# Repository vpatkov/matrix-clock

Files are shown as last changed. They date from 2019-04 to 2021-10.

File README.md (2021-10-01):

# Matrix Clock with Weather Station

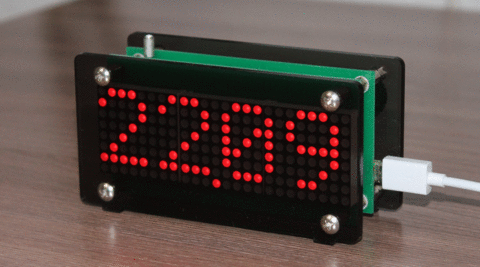
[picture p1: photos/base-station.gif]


Not too small, not too big, auto-syncing clock with wide viewing angle,
pretty bright at sunny day and not too bright at night, having a
simple weather station, without any wires except a Micro-USB power.

- Show clock, outdoor and indoor temperatures, indoor relative humidity, and
  atmospheric pressure
- Show the peak values and the change of any weather parameter for 24 hours
- Clock is wirelessly synced with a PC and maintained when the PC is offline
- Automatic brightness control
- Intuitively controlled with a single clickable rotary encoder on the back side

The project includes a base station with a LED matrix display, and two
wireless modules: one is for measuring outdoor temperature, and one is for
communication with a PC (syncing time).

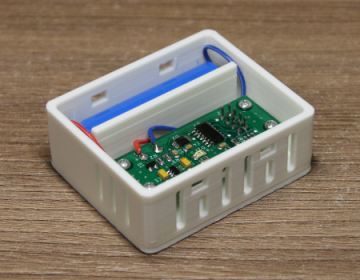
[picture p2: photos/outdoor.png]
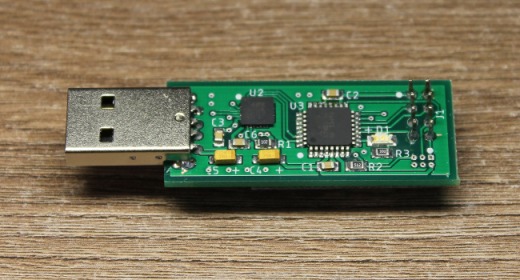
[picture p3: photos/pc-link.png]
 

If, for some reason, the base station conclude that some data is unreliable, it
show the latest reliable data with a warning mark as a point in the bottom
right corner. Clock is unreliable if not synced with a PC for a week. Outdoor
temperature is unreliable if no data was received from the outdoor sensor for
10 minutes. Data from indoor sensors is unreliable in case of any error.

If the battery in the outdoor module is low, a warning mark as a point in
the top right corner appears on the outdoor temperature screen.

It's a project I made for personal use in 2014 with some updates then.
It's based on my own preferences and ad hoc decisions. Also, it's my first
real-world electronic project after "LED blinking", and so have many design
lacks.

## Technical details

The base station is a sandwich of two boards called in sources as `base` and
`matrix`. The `base` board contains an MCU, indoor sensors, RF module, and other
peripherals. The `matrix` board is just a SPI controlled 24×8 LED matrix.

The wireless modules are called in sources as `outdoor` (outdoor temperature
measurement) and `pc-link` (communication with a PC). The `pc-link` module
is connected to a PC by USB, and appears as a virtual serial port (CP2102N chip
is used for that). CP2102N also feeds 1 MHz clock to the MCU, the chip
must be configured for that with Silabs' [configuration tool](https://www.silabs.com/products/development-tools/software/simplicity-studio).
The `pc-link` module is controlled by a host program `matrix-clock` (in the
`software` directory). Currently, the program is used just for sending
current time to the base station (add it to cron).

The wireless network is build on Nordic NRF24L01+ chips.

The front and rear glasses for the base station are made in
[Ponoko](https://www.ponoko.com/) by laser cutting from "acrylic gray tint"
material using the `case/base-station.svg` file.

The case for the outdoor module is 3D printed from the `case/outdoor-case.stl`
and `case/outdoor-cover.stl` files.

## License

Creative Commons Zero 1.0



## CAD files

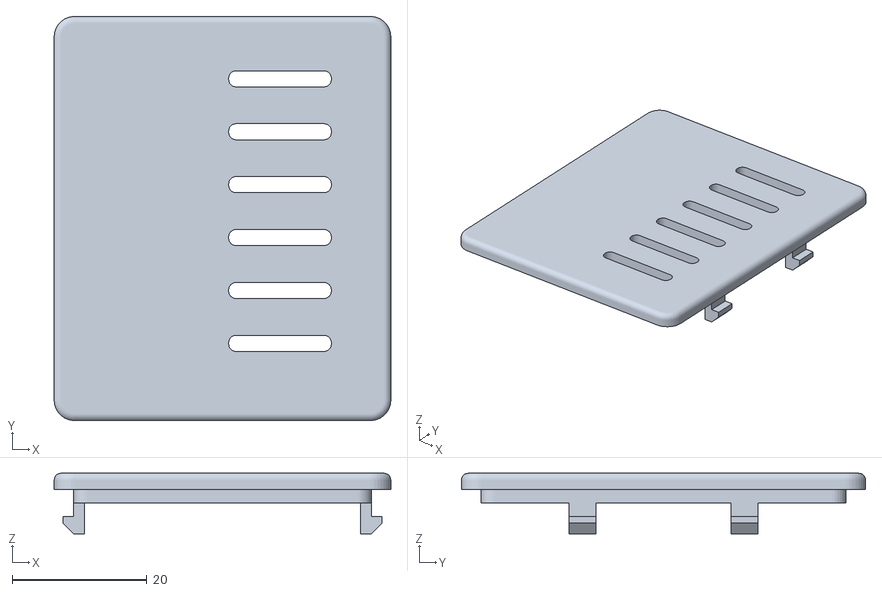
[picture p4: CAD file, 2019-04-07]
case/outdoor-cover.stl
50.0 x 60.0 x 9.00

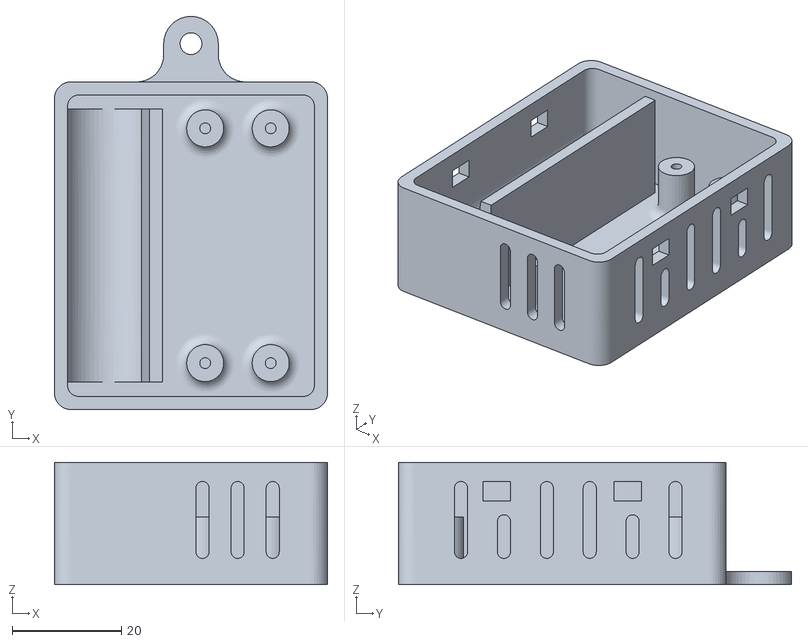
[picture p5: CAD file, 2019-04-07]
case/outdoor-case.stl
50.0 x 72.0 x 22.4

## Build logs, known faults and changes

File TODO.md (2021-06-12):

Remake from scratch:

- Don't remake wireless modules (`pc-link` and `outdoor`), they are ok.
  Some cosmetic fixes maybe.
- Single board, use small SMD components. For ISP programming use pogo pads
  (like in the wireless modules).
- Try to put all the sensors on a single bus (I2C or SPI).
- Don't use breakout boards. Maybe except NRF24L01+, but solder it directly
  (like in the wireless modules).
- Don't use 32k crystal, use a single 8M XO oscillator.
- Maybe serial interface (CP2102N) for changing settings, debugging, etc.
- Maybe emergency battery to keep the RTC. Maybe an RTC chip.
- Log weather and send it to the PC.
- CO2 sensor?
- Buzzer
- Fully enclose in a 3D printed case.

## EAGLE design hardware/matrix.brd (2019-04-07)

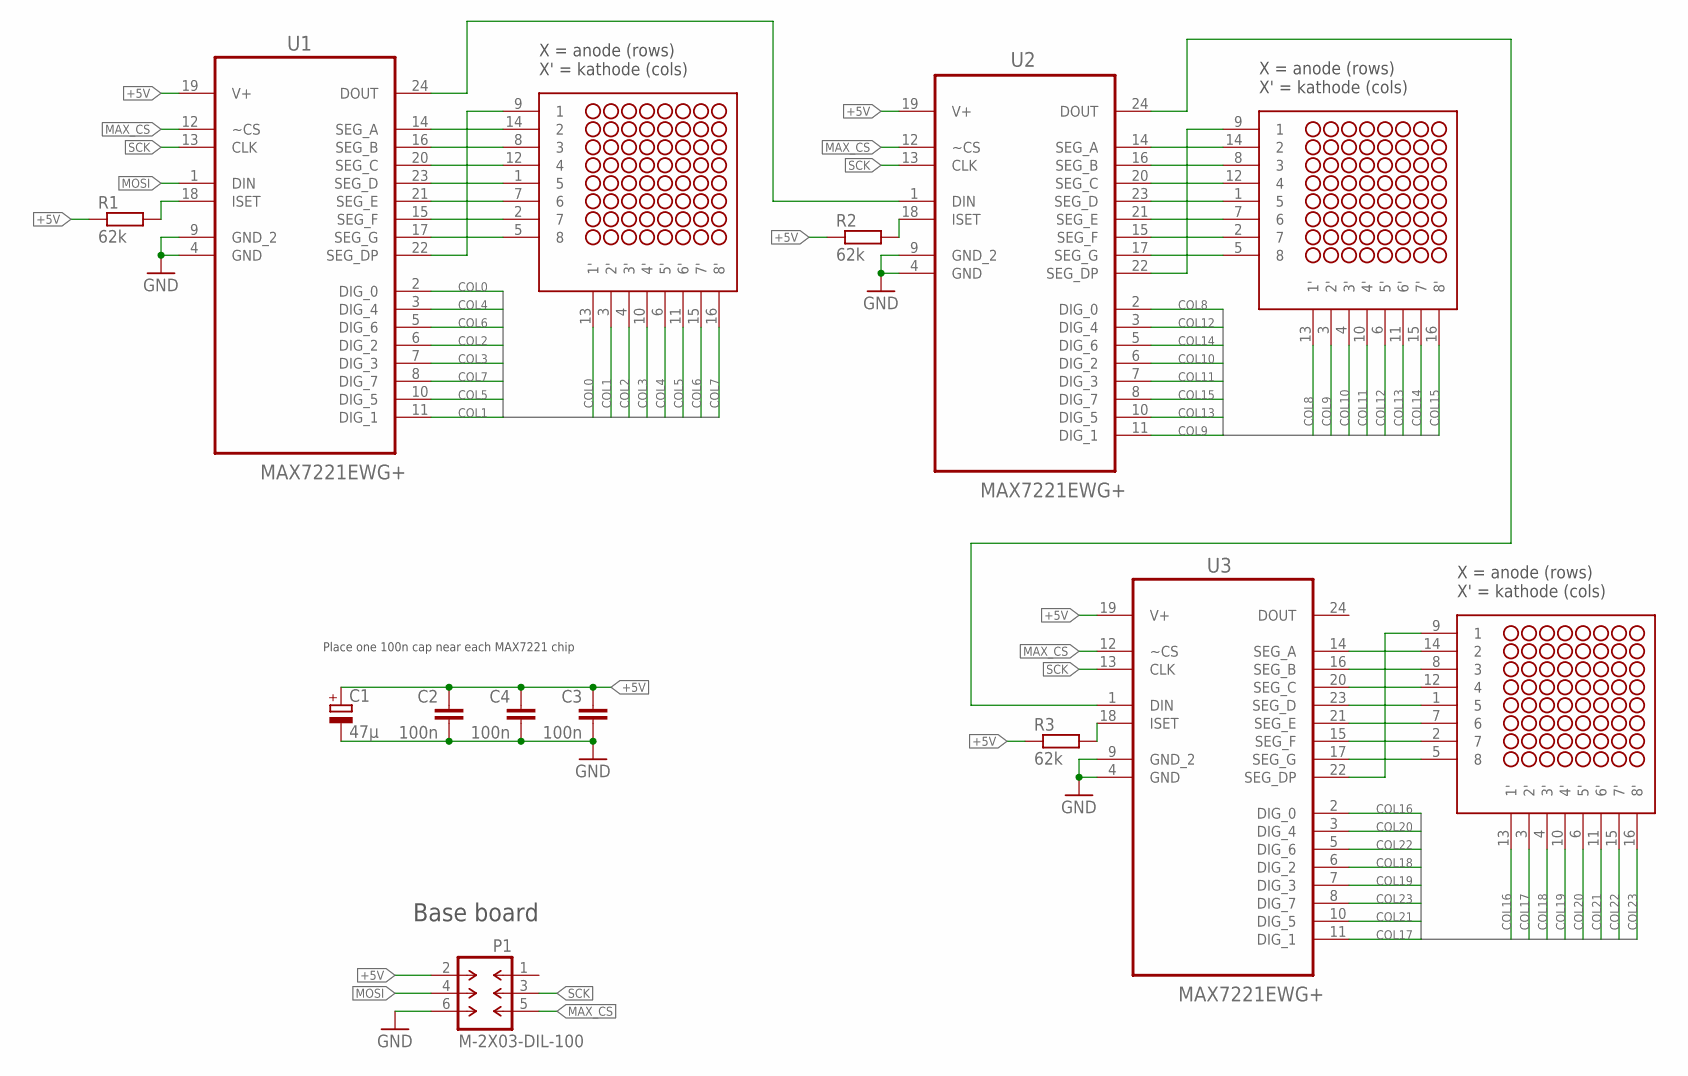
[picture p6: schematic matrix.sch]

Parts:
C1: 47μ; D/7343-31W
C2, C3, C4: 100n; C1206
M1, M2, M3: 1088BS; NFM-12881BG-11
P1: M-2X03-DIL-100; DIL-100-2X03
R1, R2, R3: 62k; R1206
U1, U2, U3: MAX7221EWG+; SOIC127P1032X265-24N

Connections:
+5V: C1.+, C2.1, C3.1, C4.1, P1.2, R1.1, R2.1, R3.1, U1.19 (V+), U2.19 (V+), U3.19 (V+)
COL0: M1.13 (1'), U1.2 (DIG_0)
COL1: M1.3 (2'), U1.11 (DIG_1)
COL2: M1.4 (3'), U1.6 (DIG_2)
COL3: M1.10 (4'), U1.7 (DIG_3)
COL4: M1.6 (5'), U1.3 (DIG_4)
COL5: M1.11 (6'), U1.10 (DIG_5)
COL6: M1.15 (7'), U1.5 (DIG_6)
COL7: M1.16 (8'), U1.8 (DIG_7)
COL8: M2.13 (1'), U2.2 (DIG_0)
COL9: M2.3 (2'), U2.11 (DIG_1)
COL10: M2.4 (3'), U2.6 (DIG_2)
COL11: M2.10 (4'), U2.7 (DIG_3)
COL12: M2.6 (5'), U2.3 (DIG_4)
COL13: M2.11 (6'), U2.10 (DIG_5)
COL14: M2.15 (7'), U2.5 (DIG_6)
COL15: M2.16 (8'), U2.8 (DIG_7)
COL16: M3.13 (1'), U3.2 (DIG_0)
COL17: M3.3 (2'), U3.11 (DIG_1)
COL18: M3.4 (3'), U3.6 (DIG_2)
COL19: M3.10 (4'), U3.7 (DIG_3)
COL20: M3.6 (5'), U3.3 (DIG_4)
COL21: M3.11 (6'), U3.10 (DIG_5)
COL22: M3.15 (7'), U3.5 (DIG_6)
COL23: M3.16 (8'), U3.8 (DIG_7)
GND: C1.-, C2.2, C3.2, C4.2, P1.6, U1.4 (GND), U1.9 (GND_2), U2.4 (GND), U2.9 (GND_2), U3.4 (GND), U3.9 (GND_2)
MAX_CS: P1.5, U1.12 (~CS), U2.12 (~CS), U3.12 (~CS)
MOSI: P1.4, U1.1 (DIN)
unnamed: M1.9 (1), U1.22 (SEG_DP)
unnamed: M1.5 (8), U1.17 (SEG_G)
unnamed: M1.2 (7), U1.15 (SEG_F)
unnamed: M1.7 (6), U1.21 (SEG_E)
unnamed: M1.1 (5), U1.23 (SEG_D)
unnamed: M1.12 (4), U1.20 (SEG_C)
unnamed: M1.8 (3), U1.16 (SEG_B)
unnamed: M1.14 (2), U1.14 (SEG_A)
unnamed: M2.9 (1), U2.22 (SEG_DP)
unnamed: M2.14 (2), U2.14 (SEG_A)
unnamed: M2.8 (3), U2.16 (SEG_B)
unnamed: M2.12 (4), U2.20 (SEG_C)
unnamed: M2.1 (5), U2.23 (SEG_D)
unnamed: M2.7 (6), U2.21 (SEG_E)
unnamed: M2.2 (7), U2.15 (SEG_F)
unnamed: M2.5 (8), U2.17 (SEG_G)
unnamed: M3.9 (1), U3.22 (SEG_DP)
unnamed: M3.5 (8), U3.17 (SEG_G)
unnamed: M3.2 (7), U3.15 (SEG_F)
unnamed: M3.7 (6), U3.21 (SEG_E)
unnamed: M3.1 (5), U3.23 (SEG_D)
unnamed: M3.12 (4), U3.20 (SEG_C)
unnamed: M3.8 (3), U3.16 (SEG_B)
unnamed: M3.14 (2), U3.14 (SEG_A)
unnamed: U1.24 (DOUT), U2.1 (DIN)
unnamed: U2.24 (DOUT), U3.1 (DIN)
unnamed: R1.2, U1.18 (ISET)
unnamed: R2.2, U2.18 (ISET)
unnamed: R3.2, U3.18 (ISET)
SCK: P1.3, U1.13 (CLK), U2.13 (CLK), U3.13 (CLK)

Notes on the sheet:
X = anode (rows) X' = kathode (cols)
Base board
Place one 100n cap near each MAX7221 chip

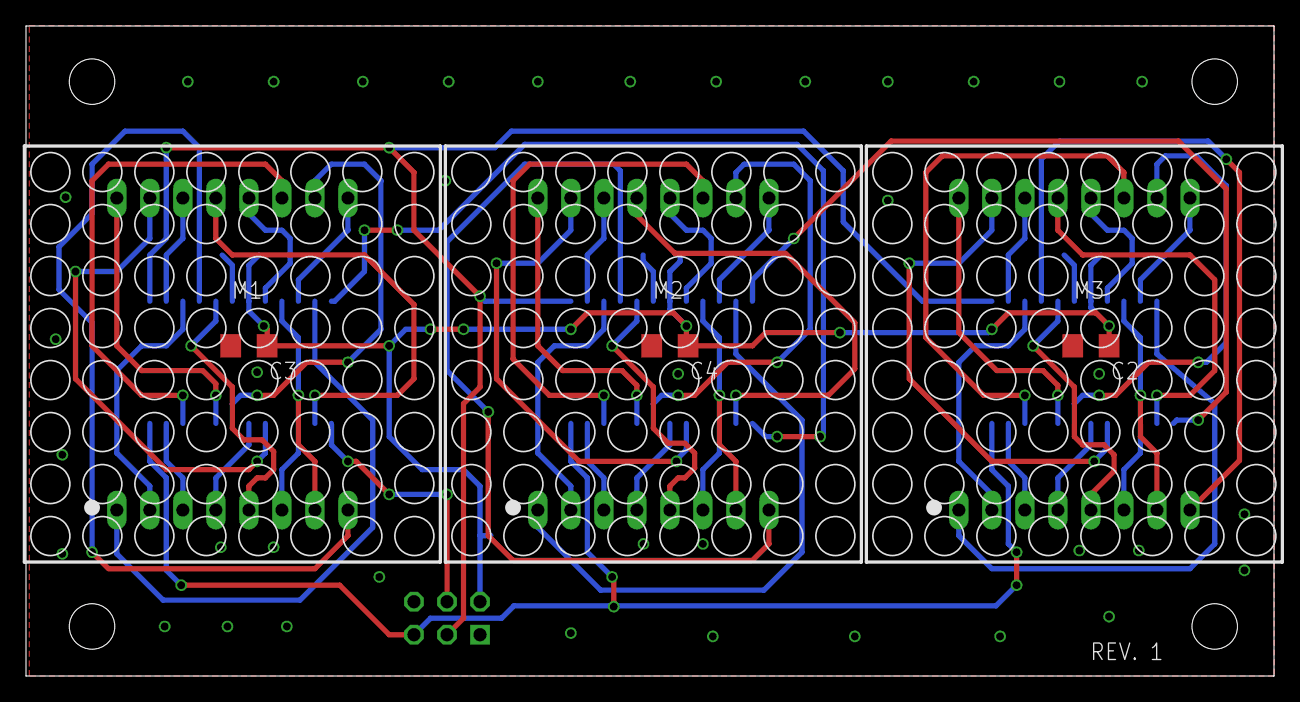
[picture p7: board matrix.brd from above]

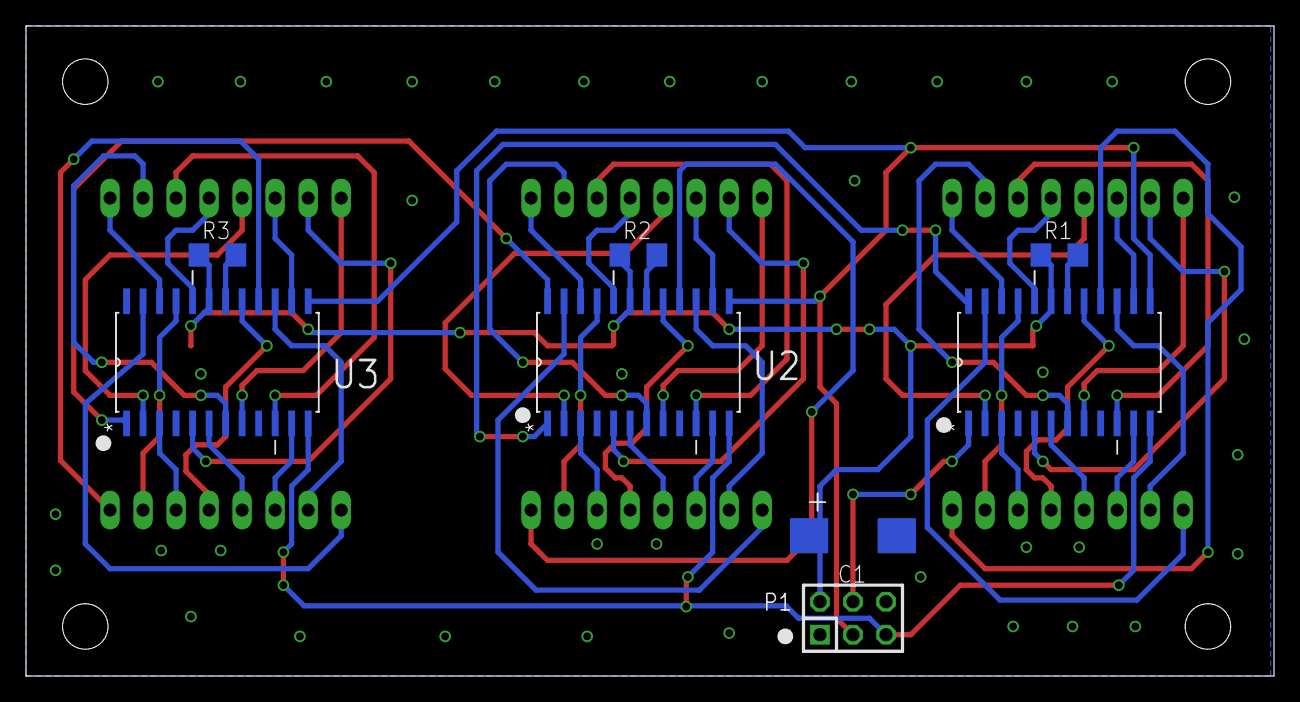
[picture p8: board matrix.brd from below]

Board: 2 copper layers, 96.0 x 50.0 mm, 14 parts (8 on the bottom side), 58 nets.

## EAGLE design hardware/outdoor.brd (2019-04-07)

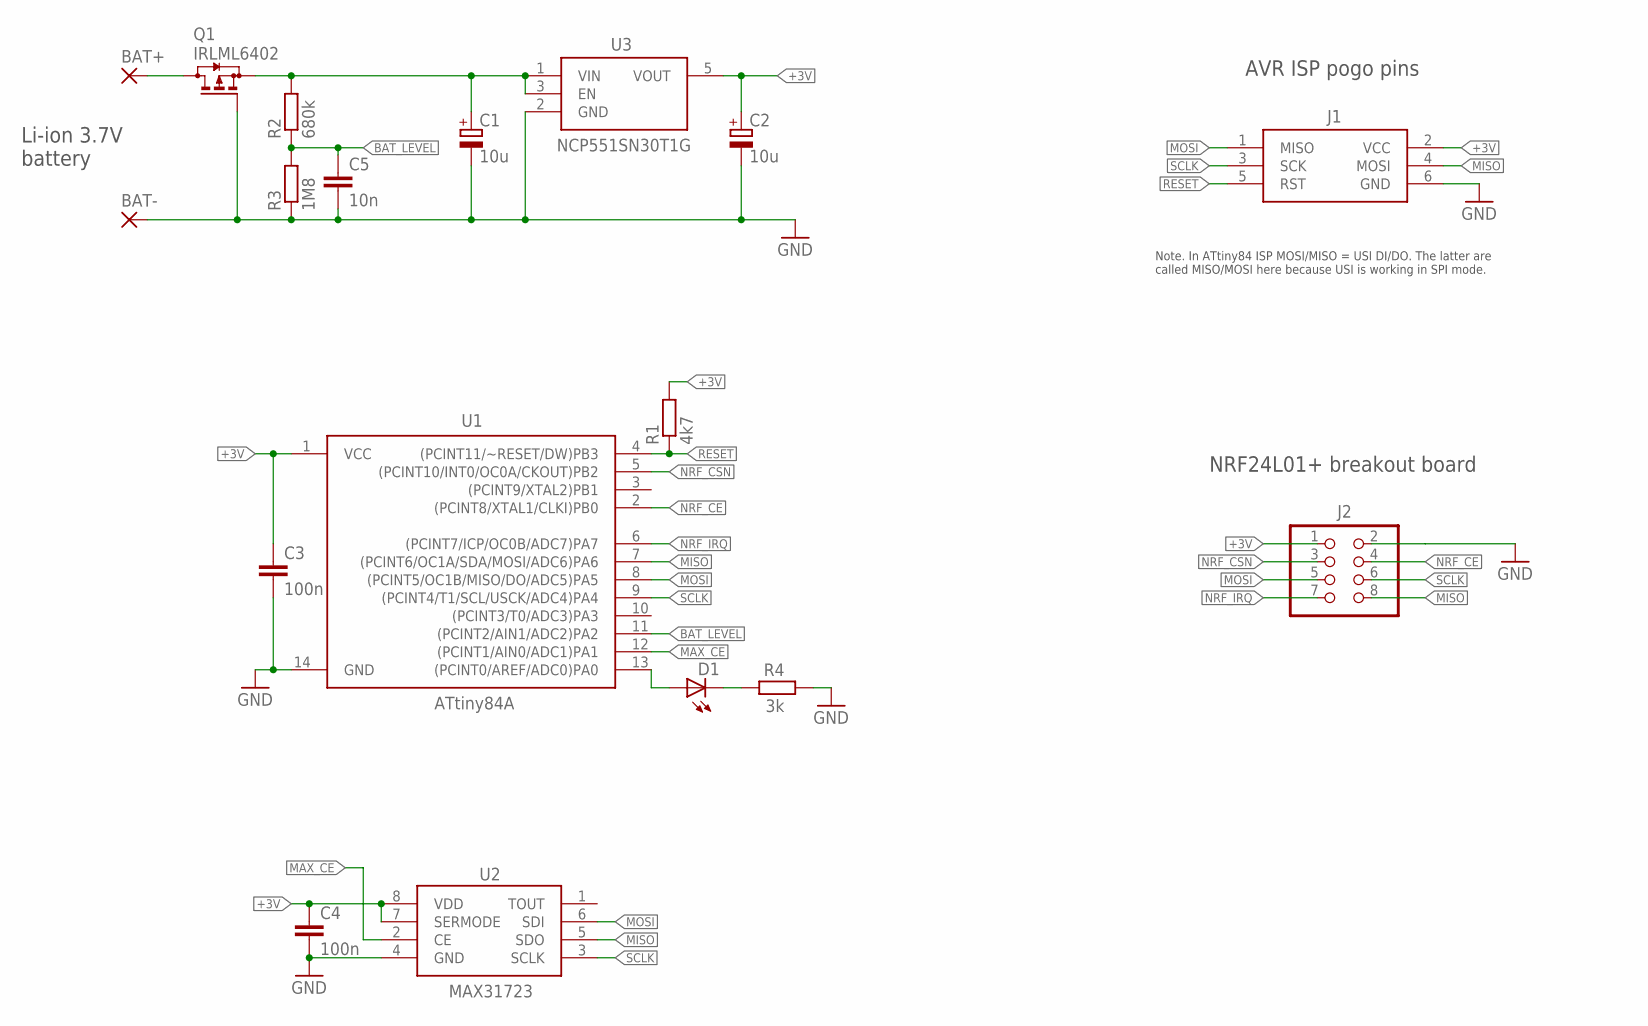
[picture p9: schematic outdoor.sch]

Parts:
BAT+: 2,54/1,0
BAT-: 2,54/1,0
C1, C2: 10u; CT3216
C3, C4: 100n; C0805
C5: 10n; C0805
D1: LEDSMT1206; 1206
J1: POGO_AVR_ISP6
J2: PINHD-2X4; 2X04
Q1: IRLML6402; SOT23
R1: 4k7; R0805
R2: 680k; R0805
R3: 1M8; R0805
R4: 3k; R0805
U1: ATtiny84A; SO14
U2: MAX31723; UMAX8
U3: NCP551SN30T1G; SOT23-5

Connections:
+3V: C2.+, C3.1, C4.1, J1.2 (VCC), J2.1, R1.2, U1.1 (VCC), U2.7 (SERMODE), U2.8 (VDD), U3.5 (VOUT)
BAT_LEVEL: C5.1, R2.1, R3.2, U1.11 ((PCINT2/AIN1/ADC2)PA2)
GND: BAT-.1, C1.-, C2.-, C3.2, C4.2, C5.2, J1.6 (GND), J2.2, Q1.1 (G), R3.1, R4.1, U1.14 (GND), U2.4 (GND), U3.2 (GND)
MAX_CE: U1.12 ((PCINT1/AIN0/ADC1)PA1), U2.2 (CE)
MISO: J1.4 (MOSI), J2.8, U1.7 ((PCINT6/OC1A/SDA/MOSI/ADC6)PA6), U2.5 (SDO)
MOSI: J1.1 (MISO), J2.5, U1.8 ((PCINT5/OC1B/MISO/DO/ADC5)PA5), U2.6 (SDI)
unnamed: BAT+.1, Q1.3 (D)
unnamed: C1.+, Q1.2 (S), R2.2, U3.1 (VIN), U3.3 (EN)
unnamed: D1.A, U1.13 ((PCINT0/AREF/ADC0)PA0)
unnamed: D1.C, R4.2
NRF_CE: J2.4, U1.2 ((PCINT8/XTAL1/CLKI)PB0)
NRF_CSN: J2.3, U1.5 ((PCINT10/INT0/OC0A/CKOUT)PB2)
NRF_IRQ: J2.7, U1.6 ((PCINT7/ICP/OC0B/ADC7)PA7)
RESET: J1.5 (RST), R1.1, U1.4 ((PCINT11/~RESET/DW)PB3)
SCLK: J1.3 (SCK), J2.6, U1.9 ((PCINT4/T1/SCL/USCK/ADC4)PA4), U2.3 (SCLK)

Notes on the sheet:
Li-ion 3.7V battery
Note. In ATtiny84 ISP MOSI/MISO = USI DI/DO. The latter are called MISO/MOSI here because USI is working in SPI mode.
AVR ISP pogo pins
NRF24L01+ breakout board

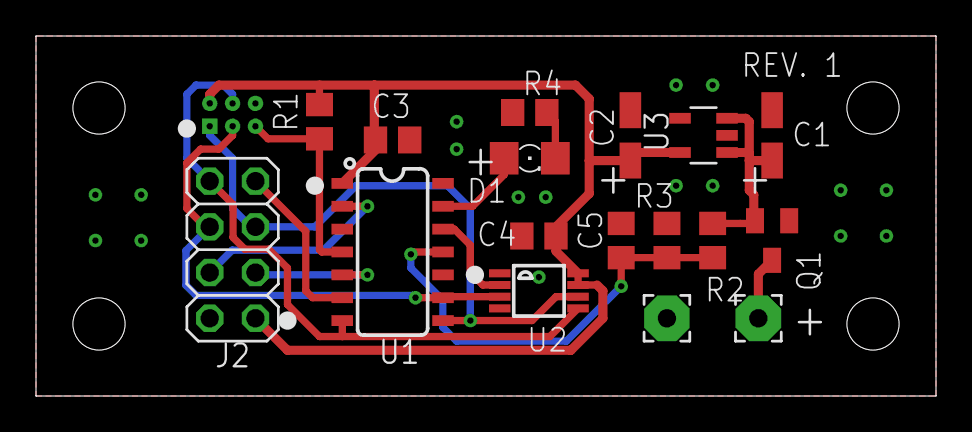
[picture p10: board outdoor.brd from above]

Board: 2 copper layers, 50.0 x 20.0 mm, 18 parts (0 on the bottom side), 15 nets.

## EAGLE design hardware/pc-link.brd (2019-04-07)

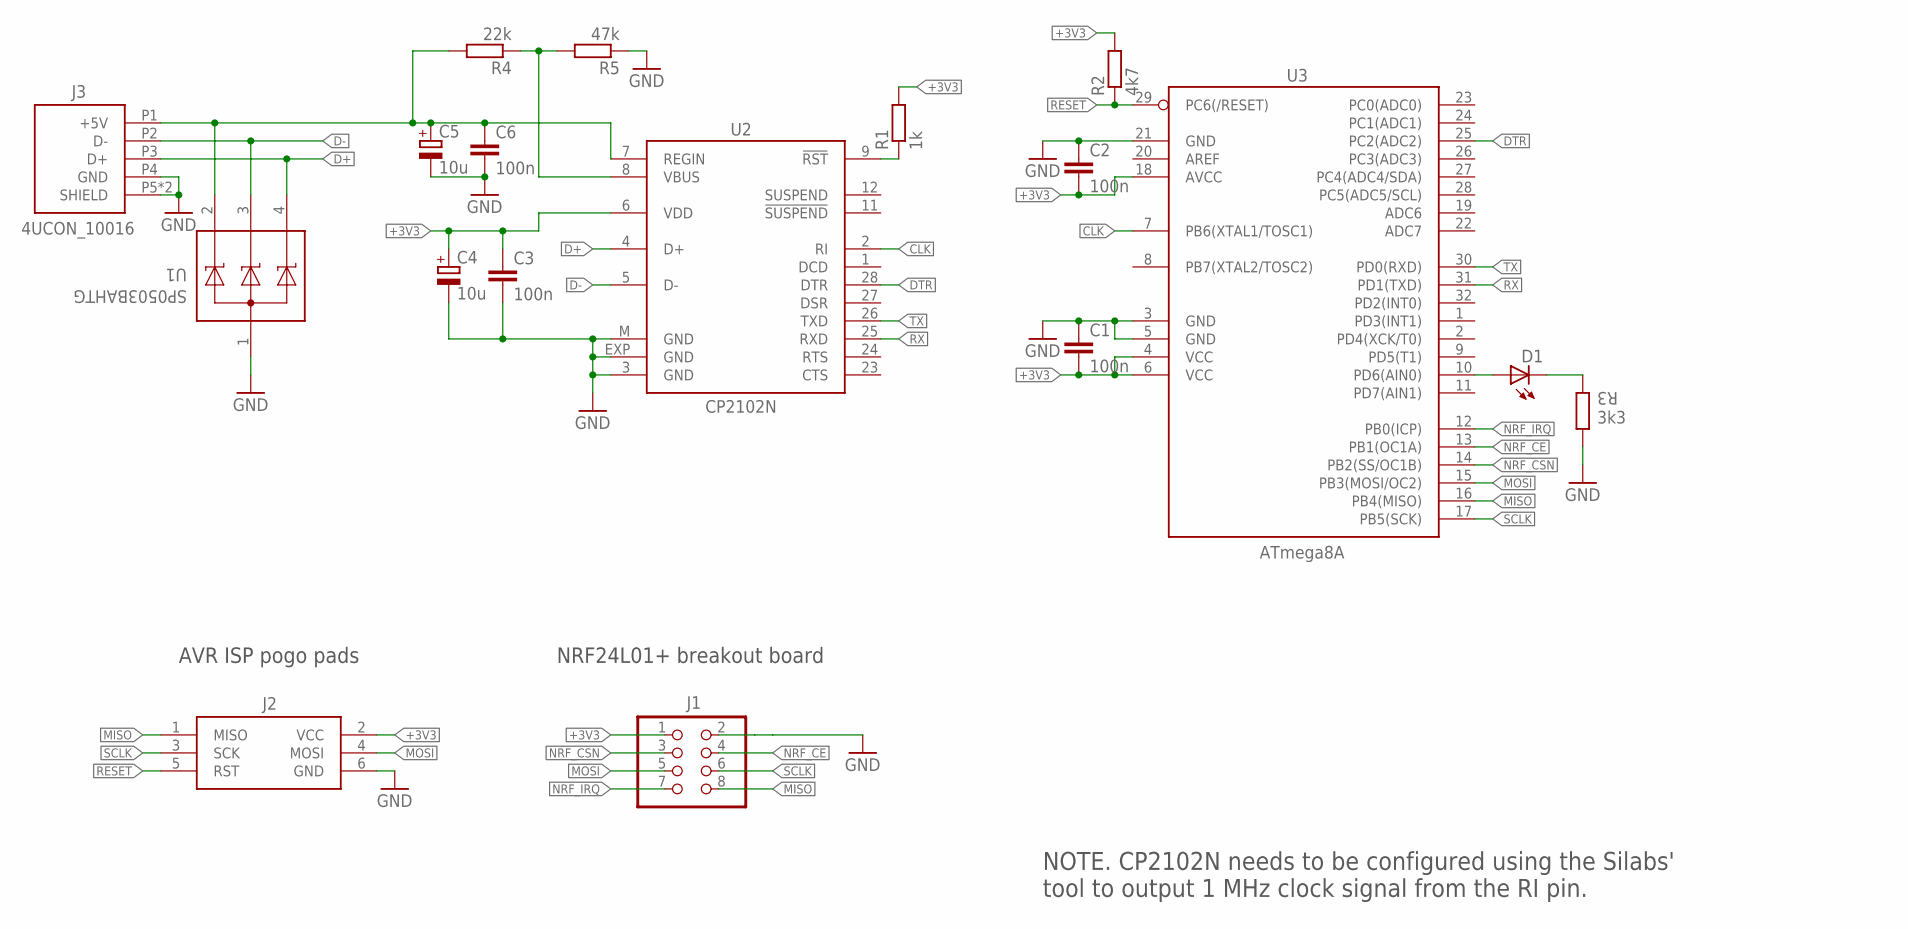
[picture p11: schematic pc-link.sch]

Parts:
C1, C2, C3, C6: 100n; C0805
C4, C5: 10u; CT3216
D1: LEDSMT1206; 1206
J1: PINHD-2X4; 2X04
J2: POGO_AVR_ISP6
J3: 4UCON_10016; USB_A_4UCON_10016
R1: 1k; R0805
R2: 4k7; R0805
R3: 3k3; R0805
R4: 22k; R0805
R5: 47k; R0805
U1: SP0503BAHTG; SOT143
U2: CP2102N; MLP28
U3: ATmega8A; TQFP32-08

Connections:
+3V3: C1.2, C2.2, C3.1, C4.+, J1.1, J2.2 (VCC), R1.2, R2.2, U2.6 (VDD), U3.4 (VCC), U3.6 (VCC), U3.18 (AVCC)
+5V: C5.+, C6.1, J3.P1 (+5V), R4.2, U1.2, U2.7 (REGIN)
CLK: U2.2 (RI), U3.7 (PB6(XTAL1/TOSC1))
D+: J3.P3 (D+), U1.4, U2.4 (D+)
D-: J3.P2 (D-), U1.3, U2.5 (D-)
DTR: U2.28 (DTR), U3.25 (PC2(ADC2))
GND: C1.1, C2.1, C3.2, C4.-, C5.-, C6.2, J1.2, J2.6 (GND), J3.P4 (GND), J3.P5 (SHIELD), J3.P6 (SHIELD), R3.1, R5.1, U1.1, U2.3 (GND), U2.EXP (GND), U2.M (GND), U3.3 (GND), U3.5 (GND), U3.21 (GND)
MISO: J1.8, J2.1 (MISO), U3.16 (PB4(MISO))
MOSI: J1.5, J2.4 (MOSI), U3.15 (PB3(MOSI/OC2))
unnamed: R1.1, U2.9 (!RST)
unnamed: D1.C, R3.2
unnamed: D1.A, U3.10 (PD6(AIN0))
unnamed: R4.1, R5.2, U2.8 (VBUS)
NRF_CE: J1.4, U3.13 (PB1(OC1A))
NRF_CSN: J1.3, U3.14 (PB2(SS/OC1B))
NRF_IRQ: J1.7, U3.12 (PB0(ICP))
RESET: J2.5 (RST), R2.1, U3.29 (PC6(/RESET))
RX: U2.25 (RXD), U3.31 (PD1(TXD))
SCLK: J1.6, J2.3 (SCK), U3.17 (PB5(SCK))
TX: U2.26 (TXD), U3.30 (PD0(RXD))

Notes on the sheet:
NOTE. CP2102N needs to be configured using the Silabs' tool to output 1 MHz clock signal from the RI pin.
NRF24L01+ breakout board
AVR ISP pogo pads

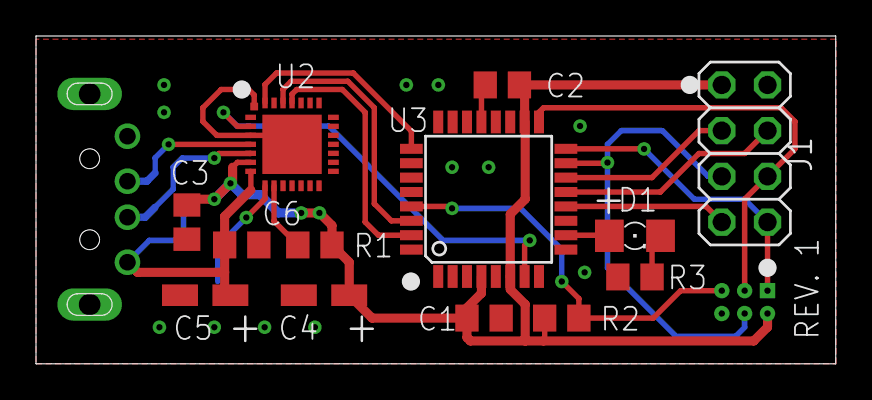
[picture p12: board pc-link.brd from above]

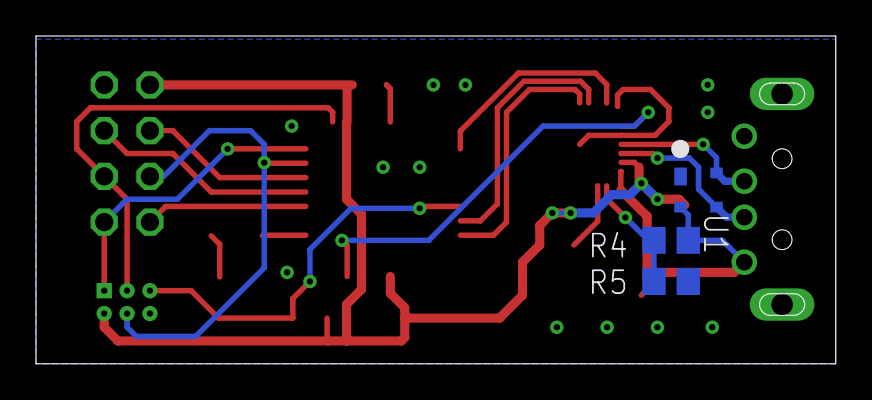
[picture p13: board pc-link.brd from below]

Board: 2 copper layers, 44.4 x 18.2 mm, 18 parts (3 on the bottom side), 20 nets.

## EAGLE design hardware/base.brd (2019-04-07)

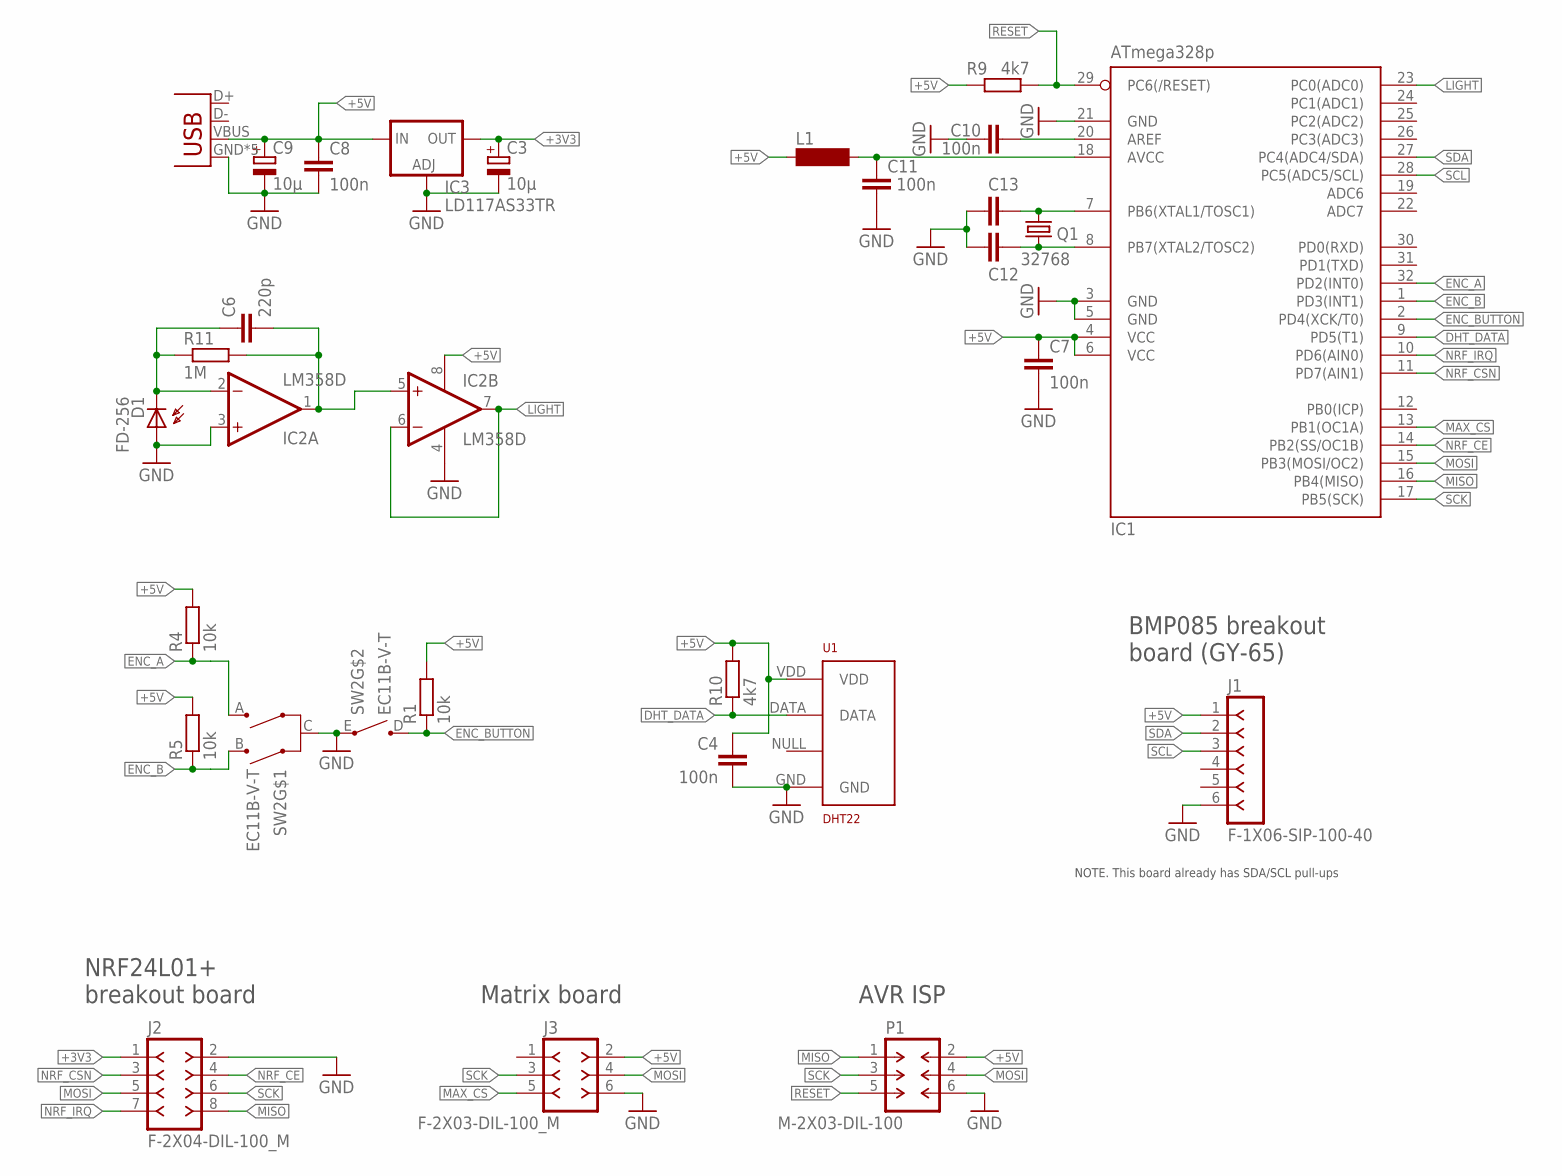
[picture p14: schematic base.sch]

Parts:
C3, C9: 10μ; D/7343-31R
C4, C8: 100n; C1206
C6: 220p; C1206
C7, C10, C11: 100n; C0805
C12, C13: C-EUC0805; C0805
D1: FD-256; BPX65
IC1: ATmega328p; TQFP32-08
IC2: LM358D; SO08
IC3: LD117AS33TR; SOT223
J1: F-1X06-SIP-100-40; SIP-100-06-40
J2: F-2X04-DIL-100_M; DIL-100-2X04_M
J3: F-2X03-DIL-100_M; DIL-100-2X03_M
JP5: USB-MICROB
L1: SM-1206
P1: M-2X03-DIL-100; DIL-100-2X03
Q1: 32768; TC26H
R1, R4, R5: 10k; R1206
R9, R10: 4k7; R1206
R11: 1M; R1206
SW2: EC11B-V-T; EC11B-V
U1: DHT22; RHT03_DHT-22/RA

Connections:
+3V3: C3.+, IC3.4 (OUT), J2.1
+5V: C4.1, C7.1, C8.1, C9.+, IC1.4 (VCC), IC1.6 (VCC), IC2.8 (V+), IC3.3 (IN), J1.1, J3.2, JP5.VBUS, L1.1, P1.2, R1.2, R4.2, R5.2, R9.2, R10.2, U1.VDD
DHT_DATA: IC1.9 (PD5(T1)), R10.1, U1.DATA
ENC_A: IC1.32 (PD2(INT0)), R4.1, SW2.A
ENC_B: IC1.1 (PD3(INT1)), R5.1, SW2.B
ENC_BUTTON: IC1.2 (PD4(XCK/T0)), R1.1, SW2.D
GND: C3.-, C4.2, C7.2, C8.2, C9.-, C10.2, C11.2, C12.2, C13.2, D1.A, IC1.3 (GND), IC1.5 (GND), IC1.21 (GND), IC2.3 (+IN), IC2.4 (V-), IC3.1 (ADJ), J1.6, J2.2, J3.6, JP5.GND, JP5.MT1 (GND), JP5.MT2 (GND), JP5.P$1 (GND), JP5.P$2 (GND), P1.6, SW2.C, SW2.E, U1.GND
LIGHT: C6.2, IC1.23 (PC0(ADC0)), IC2.1 (OUT), IC2.5 (+IN), IC2.6 (-IN), IC2.7 (OUT), R11.2
MAX_CS: IC1.13 (PB1(OC1A)), J3.5
MISO: IC1.16 (PB4(MISO)), J2.8, P1.1
MOSI: IC1.15 (PB3(MOSI/OC2)), J2.5, J3.4, P1.4
unnamed: C10.1, IC1.20 (AREF)
unnamed: C6.1, D1.K (C), IC2.2 (-IN), R11.1
unnamed: C11.1, IC1.18 (AVCC), L1.2
unnamed: C12.1, IC1.8 (PB7(XTAL2/TOSC2)), Q1.1
unnamed: C13.1, IC1.7 (PB6(XTAL1/TOSC1)), Q1.2
NRF_CE: IC1.14 (PB2(SS/OC1B)), J2.4
NRF_CSN: IC1.11 (PD7(AIN1)), J2.3
NRF_IRQ: IC1.10 (PD6(AIN0)), J2.7
RESET: IC1.29 (PC6(/RESET)), P1.5, R9.1
SCK: IC1.17 (PB5(SCK)), J2.6, J3.3, P1.3
SCL: IC1.28 (PC5(ADC5/SCL)), J1.3
SDA: IC1.27 (PC4(ADC4/SDA)), J1.2

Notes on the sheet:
BMP085 breakout board (GY-65)
NRF24L01+ breakout board
AVR ISP
Matrix board
NOTE. This board already has SDA/SCL pull-ups

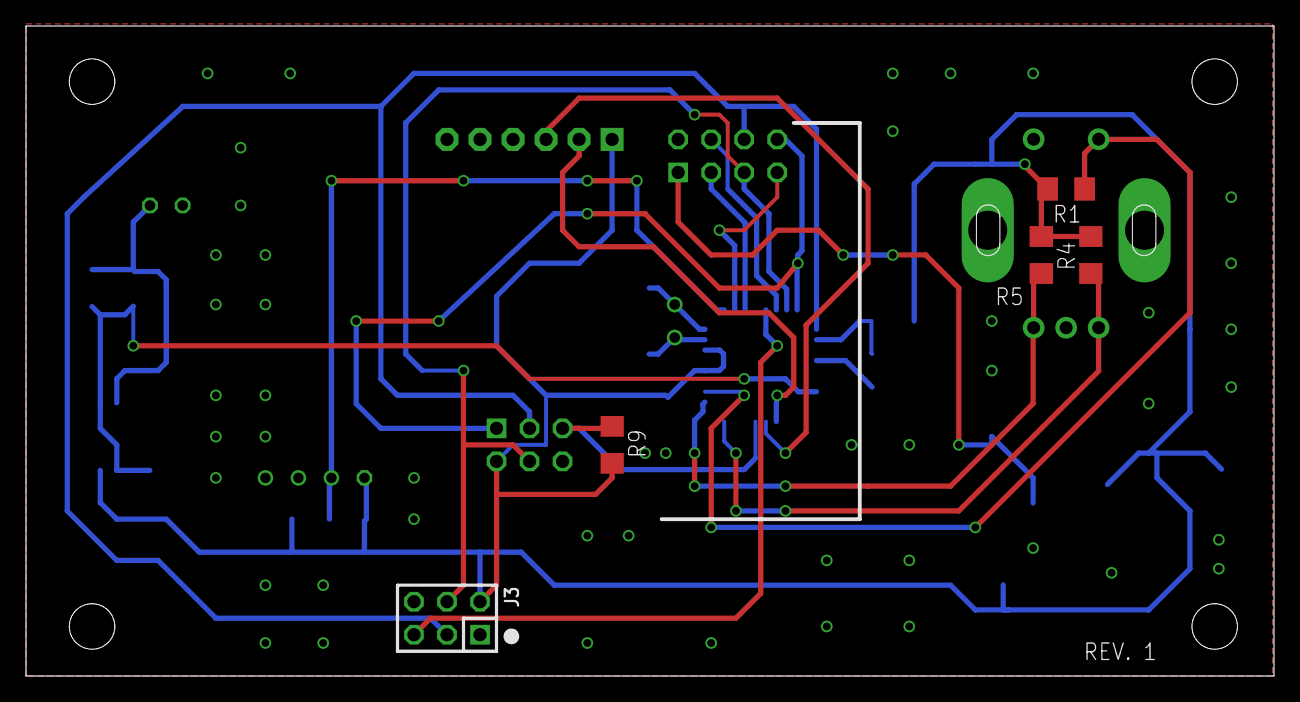
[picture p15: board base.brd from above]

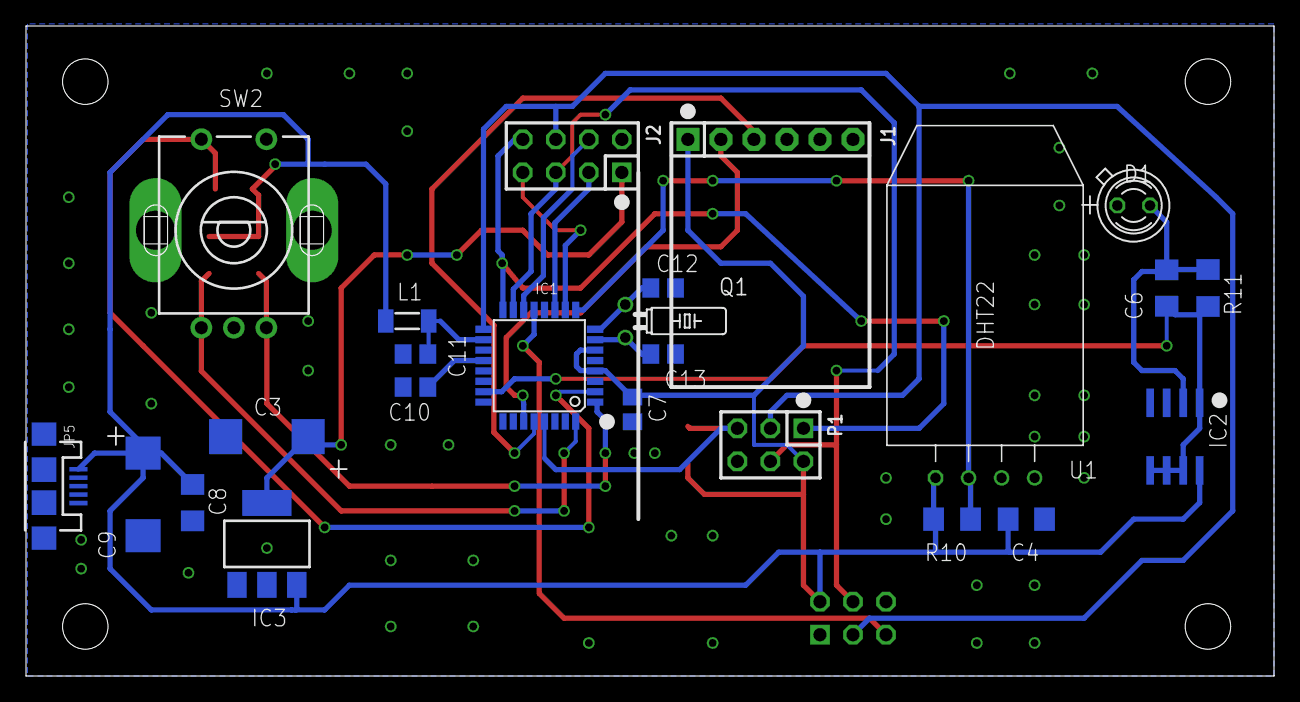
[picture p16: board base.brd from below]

Board: 2 copper layers, 96.0 x 50.0 mm, 29 parts (24 on the bottom side), 23 nets.

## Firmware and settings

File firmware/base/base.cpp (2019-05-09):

/* Main program */

#include <stdint.h>
#include <avr/io.h>
#include <avr/interrupt.h>
#include <avr/pgmspace.h>
#include "common.hpp"
#include "delay.hpp"
#include "shared.hpp"
#include "gpio.hpp"
#include "spi-hardware.hpp"
#include "matrix.hpp"
#include "max7221.hpp"
#include "dht22.hpp"
#include "i2c-hardware.hpp"
#include "bmp085.hpp"
#include "nrf24.hpp"

/* Peripherals are configured for 8 MHz system clock */
static_assert(F_CPU == 8e6, "");

constexpr Gpio::Pin max_cs = Gpio::B1;
constexpr Gpio::Pin nrf_csn = Gpio::D7, nrf_ce = Gpio::B2, nrf_irq = Gpio::D6;
constexpr Gpio::Pin dht_data = Gpio::D5;
constexpr Gpio::Pin enc_a = Gpio::D2, enc_b = Gpio::D3, enc_button = Gpio::D4;
constexpr Gpio::Pin mosi = Gpio::B3, miso = Gpio::B4, sck = Gpio::B5;

constexpr uint8_t light_adc_channel = 0;

constexpr uint32_t i2c_freq = 200e3;        /* I2C frequency (Hz) */

constexpr uint8_t full_brightness = 160;    /* Ambient light level for full matrix brightness (0..255) */
constexpr uint8_t hysteresis = 16;          /* Hysteresis of the automatic brightness control (0..255) */

constexpr int32_t outdoor_reliable_time = 10*60;        /* How long the outdoor temperature is reliable (s) */
constexpr int32_t clock_reliable_time = 7*24*3600ul;    /* How long the clock is reliable (s) */
constexpr uint8_t measure_indoor_interval = 10;         /* Interval for indoor weather measurement (s) */
constexpr uint8_t reset_screen_timeout = 10;            /* Timeout to reset screen (s) */

constexpr uint8_t history_size = 128;   /* How many weather records per day */

constexpr uint8_t low_battery_level = 3.6/4.2*255;  /* Threshold for low battery warning (0..255, 255 is 4.2 V) */

/* NRF24 network adresses and payload lengths */
constexpr uint8_t pc_link_addr[] = {0xe7, 0x4f, 0xec, 0xe8, 0x37};  /* Pipe 0 */
constexpr uint8_t pc_link_payload_length = 3;
constexpr uint8_t outdoor_addr[] = {0xc8, 0xb4, 0xe1, 0x65, 0x3b};  /* Pipe 1 */
constexpr uint8_t outdoor_payload_length = 2;

struct Weather {
        int8_t temperature_outdoor;     /* Outdoor temperature (°C) */
        int8_t temperature_indoor;      /* Indoor temperature (°C) */
        uint8_t humidity;               /* Relative humidity (%) */
        uint16_t pressure;              /* Air pressure (mmHg) */
};

struct Time {
        int8_t h, m, s;
};

enum class ScreenX: uint8_t {
        clock,
        temperature_outdoor,
        temperature_indoor,
        humidity,
        pressure,
        nr_screens
};

enum class ScreenY: uint8_t {
        current,
        change,
        minimal,
        maximal,
        nr_screens
};

struct Screen {
        ScreenX x;
        ScreenY y;
};

/* Faulty values */
constexpr int8_t bad_temperature = INT8_MAX;
constexpr uint16_t bad_pressure = UINT16_MAX;
constexpr uint8_t bad_humidity = UINT8_MAX;
constexpr Weather bad_weather = {
        .temperature_outdoor = bad_temperature,
        .temperature_indoor = bad_temperature,
        .humidity = bad_humidity,
        .pressure = bad_pressure,
};

/* Flags to control the main loop */
union Flags {
        uint16_t all;
        struct {
                bool enc_rotated_right: 1;      /* Rotary encoder was rotated right */
                bool enc_rotated_left: 1;       /* Rotary encoder was rotated left */
                bool nrf24_irq: 1;              /* NRF24 interrupt */
                bool measure_indoor: 1;         /* Measure indoor weather */
                bool refresh_screen: 1;         /* Refresh the screen */
                bool light_changed: 1;          /* Ambient light level was changed */
                bool reset_screen: 1;           /* Set screen to default (clock, current weather) */
                bool update_history: 1;         /* Save current weather to the history */
        };
};

static SpiHardware spi {mosi, miso, sck};
static Max7221 max_chain {spi, max_cs};
static Matrix matrix {max_chain};
static Nrf24 nrf24 {spi, nrf_csn, nrf_ce};
static Dht22 dht22 {dht_data};
static I2cHardware i2c;
static Bmp085 bmp085 {i2c};

static Weather weather = bad_weather;           /* Current weather */
static uint8_t battery_level;                   /* Outdoor battery level (0..255, 255 is 4.2 V) */

/* Recent update time (s_uptime) */
static int32_t outdoor_recent = -outdoor_reliable_time - 1;
static int32_t clock_recent = -clock_reliable_time - 1;

/* Weather history for the last day */
static struct {
        Weather weather[history_size];
        uint8_t current;
} history;

/* Shared variables (changed in interrupts) */
static Flags s_flags;                           /* Flags to control the main loop */
static Time s_time;                             /* Current time */
static int32_t s_uptime;                        /* Uptime (s) */
static uint8_t s_inactivity_timer;              /* User inactivity timer (s) */
static uint8_t s_light;                         /* Ambient light level (0..255) */

/* 1 Hz interrupt (RTC, timers) */
ISR(TIMER2_OVF_vect)
{
        /* RTC */
        if (++s_time.s >= 60) {
                s_time.s -= 60;
                if (++s_time.m >= 60) {
                        s_time.m -= 60;
                        if (++s_time.h >= 24)
                                s_time.h -= 24;
                }
        }

        /* Uptime */
        s_uptime++;

        /* Refresh the screen every second */
        s_flags.refresh_screen = 1;     

        /* Measure indoor weather */
        {
                static uint8_t cnt = 0;
                if (++cnt == measure_indoor_interval) {
                        cnt = 0;
                        s_flags.measure_indoor = 1;
                }
        }

        /* Update history */
        static_assert(86400 % history_size == 0, "");
        if (s_uptime % (86400/history_size) == 0)
                s_flags.update_history = 1;

        /* Reset screen by inactivity */
        if (++s_inactivity_timer == reset_screen_timeout)
                s_flags.reset_screen = 1;
}

/* ~500 Hz general-purpose interrupt */
ISR(TIMER0_OVF_vect)
{
        /* Rotary encoder */
        {
                static uint8_t cnt = 0;
                static bool prev_state = 1;
                if (Gpio::read(enc_a) != prev_state) {
                        if (++cnt > 1) {
                                if (prev_state != 0) {  /* Negative edge */
                                        if (Gpio::read(enc_b))
                                                s_flags.enc_rotated_left = 1;
                                        else
                                                s_flags.enc_rotated_right = 1;
                                }
                                prev_state = !prev_state;
                        }
                } else
                        cnt = 0;
        }

        /* NRF24 interrupt */
        if (Gpio::read(nrf_irq) == 0)
                s_flags.nrf24_irq = 1;
        
        /* Ambient light level */
        {
                static uint8_t cnt = 0;
                static uint16_t acc = 0;
                static uint8_t prev_value = 0;

                acc += ADCH;
                if (++cnt == 0) {  /* Accumulate ~0.5 seconds */
                        s_light = acc/256;
                        if (s_light != prev_value) {
                                s_flags.light_changed = 1;
                                prev_value = s_light;
                        }
                        acc = 0;
                }

                /* Start the next conversion (1.1 V reference, 62.5 kHz clock) */
                static_assert(light_adc_channel <= 7, "");
                ADMUX = 1<<REFS1 | 1<<REFS0 | 1<<ADLAR | light_adc_channel;
                ADCSRA = 1<<ADEN | 1<<ADSC | 1<<ADPS2 | 1<<ADPS1 | 1<<ADPS0;
        }
}

void nrf24_setup()
{
        /* 3-byte address, 2402 MHz, 1 Mbit/s */
        nrf24.write(Nrf24::CMD_W_REGISTER | Nrf24::REG_CONFIG,
                Nrf24::MASK_TX_DS | Nrf24::MASK_MAX_RT | Nrf24::EN_CRC |
                Nrf24::PWR_UP | Nrf24::CRC0 | Nrf24::PRIM_RX);
        nrf24.write(Nrf24::CMD_W_REGISTER | Nrf24::REG_RF_SETUP,
                Nrf24::RF_DR_1Mbps | Nrf24::RF_PWR_0dBm);
        nrf24.write(Nrf24::CMD_W_REGISTER | Nrf24::REG_FEATURE, Nrf24::EN_DYN_ACK);
        nrf24.write(Nrf24::CMD_W_REGISTER | Nrf24::REG_SETUP_AW, Nrf24::AW_5_BYTES);

        /* Enable data pipes 0 and 1 */
        nrf24.write(Nrf24::CMD_W_REGISTER | Nrf24::REG_EN_RXADDR, Nrf24::ERX_P0 | Nrf24::ERX_P1);

        /* Set the payload lengths */
        static_assert(pc_link_payload_length < 32, "");
        static_assert(outdoor_payload_length < 32, "");
        nrf24.write(Nrf24::CMD_W_REGISTER | Nrf24::REG_RX_PW_P0, pc_link_payload_length);
        nrf24.write(Nrf24::CMD_W_REGISTER | Nrf24::REG_RX_PW_P1, outdoor_payload_length);

        /* Set the addresses */
        static_assert(size(pc_link_addr) == 5, "");
        static_assert(size(outdoor_addr) == 5, "");
        nrf24.write(Nrf24::CMD_W_REGISTER | Nrf24::REG_RX_ADDR_P0, pc_link_addr, size(pc_link_addr));
        nrf24.write(Nrf24::CMD_W_REGISTER | Nrf24::REG_RX_ADDR_P1, outdoor_addr, size(outdoor_addr));

        /* Start the receiver */
        delay_ms(Nrf24::tpd2stby);
        nrf24.set_ce(1);
}

void nrf24_receive()
{
        uint8_t d[3];

        /* Stop the receiver */
        nrf24.set_ce(0);

        /* Get the received data */
        switch (nrf24.status() & Nrf24::RX_P_NO) {
        case Nrf24::RX_P_NO_0:  /* pc-link */
                nrf24.read(Nrf24::CMD_R_RX_PAYLOAD, d, 3);      /* Hours, minutes, seconds */
                atomic_block {
                        s_time.h = d[0];
                        s_time.m = d[1];
                        s_time.s = d[2];
                        clock_recent = s_uptime;
                }
                break;
        case Nrf24::RX_P_NO_1:  /* outdoor */
                nrf24.read(Nrf24::CMD_R_RX_PAYLOAD, d, 2);      /* Temperature, battery level */
                weather.temperature_outdoor = d[0];
                battery_level = d[1];
                outdoor_recent = atomic_read(s_uptime);
                break;
        }

        /* Flush the receiver and clear the interrupt flags */
        nrf24.write(Nrf24::CMD_FLUSH_RX);
        nrf24.write(Nrf24::CMD_W_REGISTER | Nrf24::REG_STATUS,
                Nrf24::RX_DR | Nrf24::TX_DS | Nrf24::MAX_RT);

        /* Start the receiver */
        nrf24.set_ce(1);
}

int main()
{
        Flags flags = {};
        Screen screen = {ScreenX::clock, ScreenY::current};
        bool temperature_indoor_reliable = false;
        bool humidity_reliable = false;
        bool pressure_reliable = false;

        /* GPIO init */
        PORTB = 0b00000011;
        DDRB  = 0b00101110;
        PORTC = 0b11001110;
        DDRC  = 0b00000000;
        PORTD = 0b10000011;
        DDRD  = 0b00000000;

        /* Disable unused peripherals */
        ACSR = 1<<ACD;
        PRR = 1<<PRTIM1 | 1<<PRUSART0;

        /* 8-bit T/C0 for the ~500 Hz interrupt */
        TCCR0B = 1<<CS01 | 1<<CS00;
        TIMSK0 |= 1<<TOIE0;

        /* 8-bit T/C2 for the 1 Hz interrupt */
        ASSR = 1<<AS2;
        TCCR2B = 1<<CS22 | 1<<CS20;
        while (ASSR & (1<<TCR2BUB))
                memory_barrier();
        TIFR2 = 1<<TOV2;
        TIMSK2 |= 1<<TOIE2;

        /* Watchdog Timer (4 s) */
        WDTCSR = 1<<WDCE | 1<<WDE;
        WDTCSR = 1<<WDE | 1<<WDP3;

        /* Other setups */
        spi.init(SpiHardware::div_16);
        max_chain.init();
        matrix.init();
        nrf24.init();
        nrf24_setup();
        dht22.init();
        bool bmp085_ok = i2c.init(i2c_freq) && bmp085.init();

        /* Clear the weather history */
        for (auto &w : history.weather)
                w = bad_weather;

        /* Initial flags */
        flags.measure_indoor = 1;
        flags.light_changed = 1;

        sei();

        while (true)
        {
                atomic_block {
                        flags.all |= s_flags.all;
                        s_flags.all = 0;
                }

                /* Indoor weather measurements */
                if (flags.measure_indoor) {
                        temperature_indoor_reliable = humidity_reliable = dht22.read();
                        if (temperature_indoor_reliable) {
                                weather.temperature_indoor = dht22.get_temperature()/10;
                                weather.humidity = dht22.get_humidity()/10;
                        }

                        pressure_reliable = bmp085_ok && bmp085.read();
                        if (pressure_reliable) {
                                weather.pressure = bmp085.get_pressure()*760/101325;
                                if (!temperature_indoor_reliable) {
                                        weather.temperature_indoor = bmp085.get_temperature()/10;
                                        temperature_indoor_reliable = true;
                                }
                        }

                        flags.measure_indoor = 0;
                        flags.refresh_screen = 1;
                }

                /* Receive data from NRF24 */
                if (flags.nrf24_irq) {
                        nrf24_receive();
                        flags.nrf24_irq = 0;
                        flags.refresh_screen = 1;
                }

                /* Rotate screens */
                if (flags.enc_rotated_left || flags.enc_rotated_right) {
                        if (Gpio::read(enc_button)) {
                                constexpr auto n = static_cast<uint8_t>(ScreenX::nr_screens);
                                const auto i = static_cast<uint8_t>(screen.x);
                                screen.x = static_cast<ScreenX>(
                                        (flags.enc_rotated_right ? i + 1 : i + n - 1) % n);
                        } else {
                                constexpr auto n = static_cast<uint8_t>(ScreenY::nr_screens);
                                const auto i = static_cast<uint8_t>(screen.y);
                                screen.y = static_cast<ScreenY>(
                                        (flags.enc_rotated_right ? i + 1 : i + n - 1) % n);
                        }

                        atomic_write(s_inactivity_timer, 0);
                        flags.enc_rotated_left = 0;
                        flags.enc_rotated_right = 0;
                        flags.refresh_screen = 1;
                }

                /* Set matrix brightness */ 
                if (flags.light_changed) {
                        static uint8_t prev_brightness = 255;
                        uint8_t adc = atomic_read(s_light);

                        /* Ambient light level -> 0..6 linearly */
                        uint8_t brightness = adc*6/full_brightness;
                        brightness = min<uint8_t>(brightness, 6);

                        /* Add hysteresis */
                        int16_t diff = adc - prev_brightness*full_brightness/6;
                        if (brightness != prev_brightness && abs(diff) > hysteresis) {
                                matrix.set_brightness(brightness*2+3);  /* Map 0..6 to 3,5..15 */
                                prev_brightness = brightness;
                        }
                        flags.light_changed = 0;
                }

                /* Reset screen */
                if (flags.reset_screen) {
                        screen.x = ScreenX::clock;
                        screen.y = ScreenY::current;
                        flags.reset_screen = 0;
                        flags.refresh_screen = 1;
                }

                /* Save current weather to the history */
                if (flags.update_history) {
                        history.weather[history.current] = weather;
                        history.current = (history.current + 1) % history_size;
                        flags.update_history = 0;
                }

                /* Show clock, current weather and warning marks */
                if (flags.refresh_screen && (screen.x == ScreenX::clock || screen.y == ScreenY::current)) {
                        switch (screen.x) {
                        case ScreenX::clock: {
                                auto time = atomic_read(s_time);
                                matrix.printf(PSTR("\r%02u%02u"), time.h, time.m);
                                matrix.draw_point(11, 0, time.s % 2);
                                auto uptime = atomic_read(s_uptime);
                                matrix.draw_point(23, 0, uptime - clock_recent > clock_reliable_time);
                                break;
                        }
                        case ScreenX::temperature_outdoor:
                                if (weather.temperature_outdoor != bad_temperature) {
                                        matrix.printf(PSTR("\rO%+3d"), weather.temperature_outdoor);
                                        auto uptime = atomic_read(s_uptime);
                                        matrix.draw_point(23, 0, uptime - outdoor_recent > outdoor_reliable_time);
                                        matrix.draw_point(23, 7, battery_level < low_battery_level);
                                } else
                                        matrix.printf(PSTR("\rO---"));
                                break;
                        case ScreenX::temperature_indoor:
                                if (weather.temperature_indoor != bad_temperature) {
                                        matrix.printf(PSTR("\rI%+3d"), weather.temperature_indoor);
                                        matrix.draw_point(23, 0, !temperature_indoor_reliable);
                                } else
                                        matrix.printf(PSTR("\rI---"));
                                break;
                        case ScreenX::humidity:
                                if (weather.humidity != bad_humidity) {
                                        matrix.printf(PSTR("\rH%3u"), weather.humidity);
                                        matrix.draw_point(23, 0, !humidity_reliable);
                                } else
                                        matrix.printf(PSTR("\rH---"));
                                break;
                        case ScreenX::pressure:
                                if (weather.pressure != bad_pressure) {
                                        matrix.printf(PSTR("\rP%3u"), weather.pressure);
                                        matrix.draw_point(23, 0, !pressure_reliable);
                                } else
                                        matrix.printf(PSTR("\rP---"));
                                break;
                        default:
                                break;
                        }

                        matrix.sync();
                        flags.refresh_screen = 0;
                }

                /* Show the weather change for 24 hours */
                if (flags.refresh_screen && screen.x != ScreenX::clock && screen.y == ScreenY::change) {
                        Weather old = history.weather[(history.current + 1) % history_size];
                        int16_t diff = INT16_MAX;

                        switch (screen.x) {
                        case ScreenX::temperature_outdoor:
                                if (weather.temperature_outdoor != bad_temperature
                                                && old.temperature_outdoor != bad_temperature)
                                        diff = weather.temperature_outdoor - old.temperature_outdoor;
                                break;
                        case ScreenX::temperature_indoor:
                                if (weather.temperature_indoor != bad_temperature
                                                && old.temperature_indoor != bad_temperature)
                                        diff = weather.temperature_indoor - old.temperature_indoor;
                                break;
                        case ScreenX::humidity:
                                if (weather.humidity != bad_humidity
                                                && old.humidity != bad_humidity)
                                        diff = weather.humidity - old.humidity;
                                break;
                        case ScreenX::pressure:
                                if (weather.pressure != bad_pressure
                                                && old.pressure != bad_pressure)
                                        diff = weather.pressure - old.pressure;
                                break;
                        default:
                                break;
                        }

                        if (diff != INT16_MAX) {
                                matrix.printf(
                                        PSTR("\r%c%3u"),
                                        diff < 0 ? Matrix::special_down_arrow : Matrix::special_up_arrow,
                                        abs(diff));
                        } else
                                matrix.printf(PSTR("\r%c---"), Matrix::special_up_arrow);

                        matrix.sync();
                        flags.refresh_screen = 0;
                }

                /* Show minimal values of weather parameters for 24 hours */
                if (flags.refresh_screen && screen.x != ScreenX::clock && screen.y == ScreenY::minimal) {
                        switch (screen.x) {
                        case ScreenX::temperature_outdoor: {
                                auto m = weather.temperature_outdoor;
                                for (const auto &w : history.weather)
                                        if (w.temperature_outdoor != bad_temperature)
                                                m = min(m, w.temperature_outdoor);
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

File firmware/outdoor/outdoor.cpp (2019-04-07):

/* Main program */

#include <stdint.h>
#include <avr/io.h>
#include <avr/interrupt.h>
#include <avr/sleep.h>
#include "common.hpp"
#include "delay.hpp"
#include "shared.hpp"
#include "gpio.hpp"
#include "spi-usi.hpp"
#include "nrf24.hpp"
#include "max31723.hpp"

/* Peripherals are configured for 1 MHz system clock */
static_assert(F_CPU == 1e6, "");

constexpr Gpio::Pin usi_di = Gpio::A6, usi_do = Gpio::A5, usi_usck = Gpio::A4;
constexpr Gpio::Pin nrf_csn = Gpio::B2, nrf_ce = Gpio::B0, nrf_irq = Gpio::A7;
constexpr Gpio::Pin max_ce = Gpio::A1;
constexpr Gpio::Pin led = Gpio::A0;

constexpr uint8_t battery_adc_channel = 2;

constexpr uint8_t my_addr[] = {0xc8, 0xb4, 0xe1, 0x65, 0x3b};

static SpiUsi spi {usi_do, usi_di, usi_usck};
static Nrf24 nrf24 {spi, nrf_csn, nrf_ce};
static Max31723 max31723 {spi, max_ce};

EMPTY_INTERRUPT(WATCHDOG_vect);  /* Wake up only */

static void nrf24_setup()
{
        /* 3-byte address, 2402 MHz, 1 Mbit/s */
        nrf24.write(Nrf24::CMD_W_REGISTER | Nrf24::REG_EN_RXADDR, Nrf24::ERX_P0);
        nrf24.write(Nrf24::CMD_W_REGISTER | Nrf24::REG_RF_SETUP,
                Nrf24::RF_DR_1Mbps | Nrf24::RF_PWR_0dBm);
        nrf24.write(Nrf24::CMD_W_REGISTER | Nrf24::REG_FEATURE, Nrf24::EN_DYN_ACK);
        nrf24.write(Nrf24::CMD_W_REGISTER | Nrf24::REG_SETUP_AW, Nrf24::AW_5_BYTES);

        /* Set my address */
        static_assert(size(my_addr) == 5, "");
        nrf24.write(Nrf24::CMD_W_REGISTER | Nrf24::REG_TX_ADDR, my_addr, size(my_addr));
        nrf24.write(Nrf24::CMD_W_REGISTER | Nrf24::REG_RX_ADDR_P0, my_addr, size(my_addr));
}

static void nrf24_power(bool on)
{
        nrf24.write(Nrf24::CMD_W_REGISTER | Nrf24::REG_CONFIG,
                on ?
                Nrf24::MASK_RX_DR | Nrf24::MASK_TX_DS | Nrf24::MASK_MAX_RT |
                Nrf24::EN_CRC | Nrf24::PWR_UP | Nrf24::CRC0
                :
                Nrf24::MASK_RX_DR | Nrf24::MASK_TX_DS | Nrf24::MASK_MAX_RT |
                Nrf24::EN_CRC | Nrf24::CRC0);
}

static void nrf24_transmit(int8_t temperature, uint8_t battery_level)
{
        /* Power up the RF chip */
        nrf24_power(1);
        delay_ms(Nrf24::tpd2stby);

        /* Flush TX FIFO */
        nrf24.write(Nrf24::CMD_FLUSH_TX);

        /* Transmit the data */
        const uint8_t d[] = {static_cast<uint8_t>(temperature), battery_level};
        nrf24.write(Nrf24::CMD_W_TX_PAYLOAD_NOACK, d, size(d));
        nrf24.ce_pulse();

        /* Wait until done */
        while ((nrf24.status() & (Nrf24::TX_DS | Nrf24::MAX_RT)) == 0)
                memory_barrier();

        /* Clear interrupt flags */
        nrf24.write(Nrf24::CMD_W_REGISTER | Nrf24::REG_STATUS,
                Nrf24::RX_DR | Nrf24::TX_DS | Nrf24::MAX_RT); 

        /* Shut down the RF chip */
        nrf24_power(0);
}

static int8_t get_temperature()
{
        /* Start a single conversion */
        max31723.write(Max31723::REG_CONF_STATUS,
                Max31723::CONF_STATUS_1SHOT | Max31723::CONF_STATUS_SD);

        /* Wait until done */
        delay_ms(25);
        while (max31723.read(Max31723::REG_CONF_STATUS) & Max31723::CONF_STATUS_1SHOT)
                memory_barrier();

        /* Return the MSB (°C, signed) */
        return max31723.read(Max31723::REG_TEMPERATURE_MSB);
}

static uint8_t get_battery_level()
{
        /* Power up the ADC */
        PRR &= ~(1<<PRADC);

        /* Start a single conversion (VCC reference, 125 kHz clock) */
        ADCSRA = 1<<ADEN | 1<<ADSC | 1<<ADPS1 | 1<<ADPS0;

        /* Wait until done */
        while (ADCSRA & (1<<ADSC))
                memory_barrier();

        /* Read the MSB */
        uint8_t msb = ADCH;

        /* Shut down the ADC */
        ADCSRA = 0;
        PRR |= 1<<PRADC;

        return msb;
}

int main()
{
        /* GPIO init */
        PORTA = 0b00001000;
        DDRA  = 0b00110011;
        PORTB = 0b11110110;
        DDRB  = 0b00000101;

        /* Disable unused peripherals */
        ACSR = 1<<ACD;
        PRR = 1<<PRTIM1 | 1<<PRTIM0;

        /* Watchdog interrupt every 8 sec */
        WDTCSR = 1<<WDIF | 1<<WDIE | 1<<WDP3 | 1<<WDP0;

        /* ADC setup */
        static_assert(battery_adc_channel <= 7, "");
        ADMUX = battery_adc_channel;
        ADCSRB = 1<<ADLAR;

        /* Other setups */
        spi.init();
        max31723.init();
        nrf24.init();
        nrf24_setup();
        set_sleep_mode(SLEEP_MODE_PWR_DOWN);
        sei();

        delay_ms(500);  /* Skip transients */

        for (uint8_t cnt = 0; ; cnt++) {
                if ((cnt % 32) == 0) {  /* Every 256 sec */
                        int8_t temp = get_temperature();
                        uint8_t bat = get_battery_level();
                        nrf24_transmit(temp, bat);
                }
                sleep_mode();
        }

        return 0;  /* Never be here */
}

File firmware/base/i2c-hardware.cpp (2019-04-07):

#include <avr/io.h>
#include <util/twi.h>
#include "i2c-hardware.hpp"
#include "common.hpp"
#include "shared.hpp"

static inline void twi_wait()
{
        while ((TWCR & 1<<TWINT) == 0)
                memory_barrier();
}

static uint8_t start()
{
        TWCR = 1<<TWINT | 1<<TWSTA | 1<<TWEN;
        twi_wait();
        return TW_STATUS;
}

static void stop()
{
        TWCR = 1<<TWINT | 1<<TWSTO | 1<<TWEN;
        while (TWCR & 1<<TWSTO)
                memory_barrier();
}

/* Single byte write */
static uint8_t write(uint8_t byte)
{
        TWDR = byte;
        TWCR = 1<<TWINT | 1<<TWEN;
        twi_wait();
        return TW_STATUS;
}

/* Single byte read */
static uint8_t read(bool ack)
{
        TWCR = ack ? (1<<TWINT | 1<<TWEA | 1<<TWEN) : (1<<TWINT | 1<<TWEN);
        twi_wait();
        return TWDR;
}

bool I2cHardware::init(uint32_t freq)
{
        if (freq < F_CPU/526 || freq > F_CPU/16)
                return false;
        TWCR = 0;
        TWSR = 0;
        TWBR = (F_CPU/freq-16)/2;
        return true;
}

void I2cHardware::deinit()
{
        TWCR = 0;
}

/* Bulk write */
static size_t write(const uint8_t *data, size_t len)
{
        size_t written;
        for (written = 0; written < len; written++)
                if (::write(*data++) != TW_MT_DATA_ACK)
                        break;
        return written;
}

/* Bulk read */
static size_t read(uint8_t *data, size_t len)
{
        size_t readen;
        for (readen = 0; readen < len; readen++) {
                bool last = (readen == len-1);
                *data++ = ::read(last ? false : true);
                if (TW_STATUS != (last ? TW_MR_DATA_NACK : TW_MR_DATA_ACK))
                        break;
        }
        return readen;
}

/* Write transaction: START SLA+W (DATA ack)... [STOP] */
size_t I2cHardware::write(uint8_t addr, const uint8_t *data, size_t len, bool make_stop)
{
        size_t written;

        uint8_t t = start();
        if ((t != TW_START && t != TW_REP_START) || ::write((addr << 1) | TW_WRITE) != TW_MT_SLA_ACK) {
                stop();
                return 0;
        }
        if ((written = ::write(data, len)) != len || make_stop)
                stop();

        return written;
}

/* Read transaction: START SLA+R [data ACK]... (data NACK) [STOP] */
size_t I2cHardware::read(uint8_t addr, uint8_t *data, size_t len, bool make_stop)
{
        size_t readen;

        uint8_t t = start();
        if ((t != TW_START && t != TW_REP_START) || ::write((addr << 1) | TW_READ) != TW_MR_SLA_ACK) {
                stop();
                return 0;
        }
        if ((readen = ::read(data, len)) != len || make_stop)
                stop();

        return readen;
}

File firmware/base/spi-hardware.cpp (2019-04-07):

#include <avr/io.h>
#include "spi-hardware.hpp"
#include "common.hpp"
#include "shared.hpp"

SpiHardware::SpiHardware(Gpio::Pin mosi_, Gpio::Pin miso_, Gpio::Pin sck_):
        mosi(mosi_), miso(miso_), sck(sck_) {}

void SpiHardware::init(Divider div, Mode m)
{
        Gpio::write(mosi, 0);
        Gpio::set(miso, Gpio::tri);
        SPCR = 1<<SPE | 1<<MSTR | (div & 3);
        set_bits(SPSR, 1<<SPI2X, div == div_2);
        set_mode(m);
}

uint8_t SpiHardware::transfer(uint8_t out)
{
        SPDR = out;
        while ((SPSR & 1<<SPIF) == 0)
                memory_barrier();
        return SPDR;
}

void SpiHardware::set_mode(Mode m)
{
        set_bits(SPCR, 1<<CPOL, m.cpol);
        set_bits(SPCR, 1<<CPHA, m.cpha);
        set_bits(SPCR, 1<<DORD, !m.msb_first);
        Gpio::write(sck, m.cpol);
}

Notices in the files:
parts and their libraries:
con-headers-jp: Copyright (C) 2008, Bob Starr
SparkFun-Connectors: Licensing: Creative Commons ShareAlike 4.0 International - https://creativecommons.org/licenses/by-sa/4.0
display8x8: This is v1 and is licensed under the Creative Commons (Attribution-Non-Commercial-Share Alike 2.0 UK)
